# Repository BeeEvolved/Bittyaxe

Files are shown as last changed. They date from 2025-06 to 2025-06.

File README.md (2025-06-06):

<p align="center">
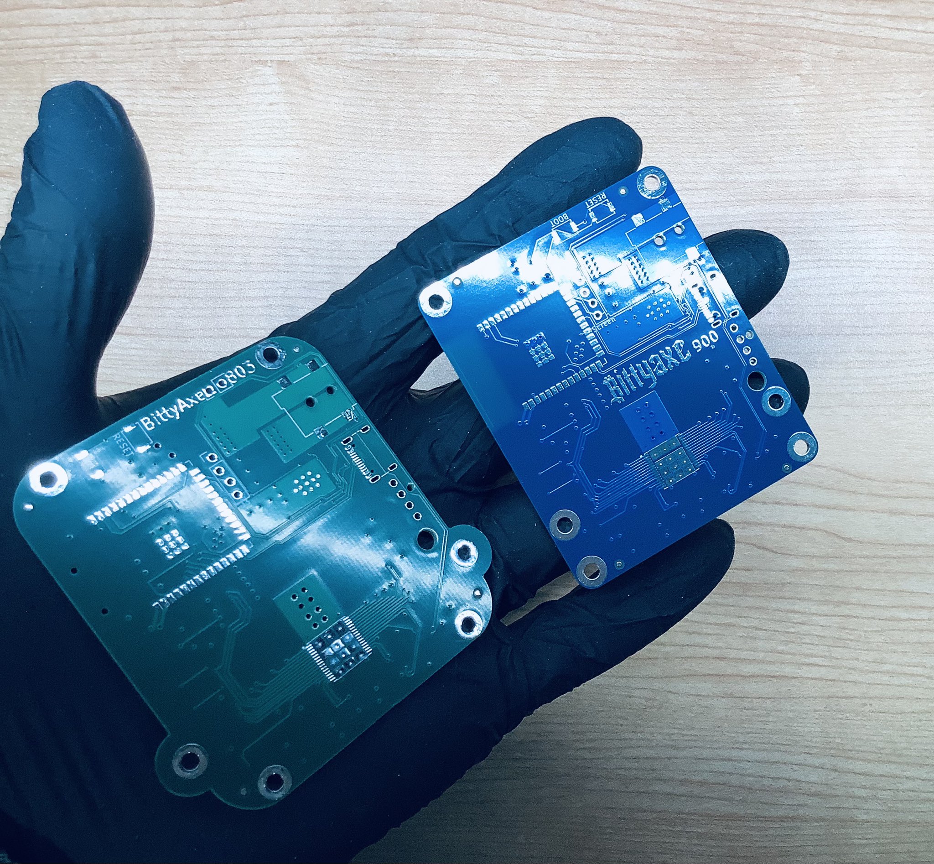
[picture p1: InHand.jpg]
Bittyaxe logo
  
</p>
<h1 align="center">itty-bitty open-source Bitcoin miner</h1>

The **BittyAxe** is a compact ASIC miner inspired by the [BitAxe Gamma](https://github.com/bitaxeorg/bitaxeGamma) design. It harnesses the power of the **BM1370** ASIC chip to achieve hash rates of approximately **1.2 TH/s** with an energy efficiency of **15 J/TH**.

---

## Features
- Custom, open-source compact thermal solution specifically designed for the BittyAxe
- Compact, space-saving form factor
- High-performance BM1370 ASIC chip
- ~1.2 TH/s hash rate
- 15 J/TH energy efficiency

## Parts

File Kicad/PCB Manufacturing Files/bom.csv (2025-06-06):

Designator | Footprint | Quantity | Value | LCSC Part #
C1, C21, C22, C23, C26, C27, C28, C30, C31, C32, C33, C34, C35, C36, C39, C40, C41, C42, C44, C45, C46, C48, C5, C7 | 0402 | 24 | 1uF
C10 | 0402 | 1 | 4.7uF
C11 | 0805 | 1 | 1000pF
C12, C25, C29, C37, C38, C47, C49, C52, C53, C8 | 0402 | 10 | 0.1uF
C13 | 0402 | 1 | 100pF
C14, C15, C16 | 0805 | 3 | 22uF
C17, C18, C19, C20, C43 | 1206 | 5 | 100uF
C2, C24 | 0805 | 2 | 10uF
C3, C4 | 1210 | 2 | 47uF
C50 | 0402 | 1 | 470pF
C6 | 0402 | 1 | 4700pF
C9 | 0402 | 1 | 2200pF
J1 | TENSILITY_54-00164 | 1 | 54-00164 | C431534
J5 | USB_C_Receptacle_GCT_USB4105-xx-A | 1 | USB_C_Receptacle_USB2.0
J6 | 470531000 | 1 | Conn_01x04
L1 | SLC1175-271MEC_COC | 1 | 300nH
R1 | 0402 | 1 | 8.25k
R10 | 0402 | 1 | 68.1k
R11 | 0402 | 1 | 10
R12 | 1206 | 1 | 1
R13, R14 | 0402 | 2 | 49.9
R15, R16, R17, R25 | 0402 | 4 | 10k
R19 | 0402 | 1 | 1k
R22, R23 | 0402 | 2 | 100
R24 | 0402 | 1 | 5.6k
R5 | 0402 | 1 | 14.7k
R6 | 0402 | 1 | RES 0 OHM JUMPER 1/16W
R8 | 0402 | 1 | 3.74k
R9 | 0402 | 1 | 11.8k
SCREEN | PinHeader_1x04_P2.54mm_Vertical_shifted | 1 | Conn_01x04
SW1, SW2 | SW_CS1213AGF260_CRS | 2 | GT-TC029B-H025-L1N
U10 | TSSOP-8_3x3mm_P0.65mm | 1 | EMC2101
U2 | LQFN40-CLIP | 1 | TPS546D24ARVFR
U3 | RT9080-33GJ5 | 1 | RT9080-33GJ5
U4 | ESP32-S3-WROOM-1 | 1 | ESP32-S3-WROOM-1
U5 | SOT-23-5 | 1 | MCP1824T-1202E/OT
U6 | SOT-23-5 | 1 | MCP1824T-0802E
U7 | SMD3225-4P | 1 | 25MHz | C5137262
U8 | BM1370 | 1 | BM1370_mode1
U9 | TSSOP-16_4.4x5mm_P0.65mm | 1 | SN74AVC4T774

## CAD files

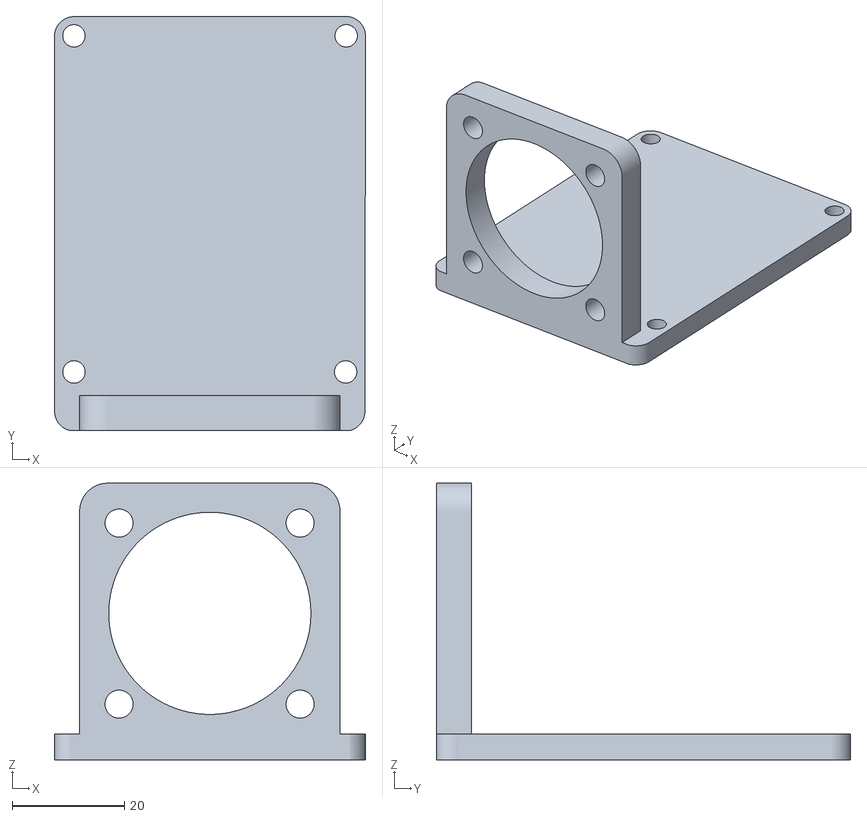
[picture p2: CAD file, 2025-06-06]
3D Print/Bittyaxe Air-Cooled Stand/Bittyaxe Air-Cooled Stand.stl
55.5 x 73.9 x 49.4

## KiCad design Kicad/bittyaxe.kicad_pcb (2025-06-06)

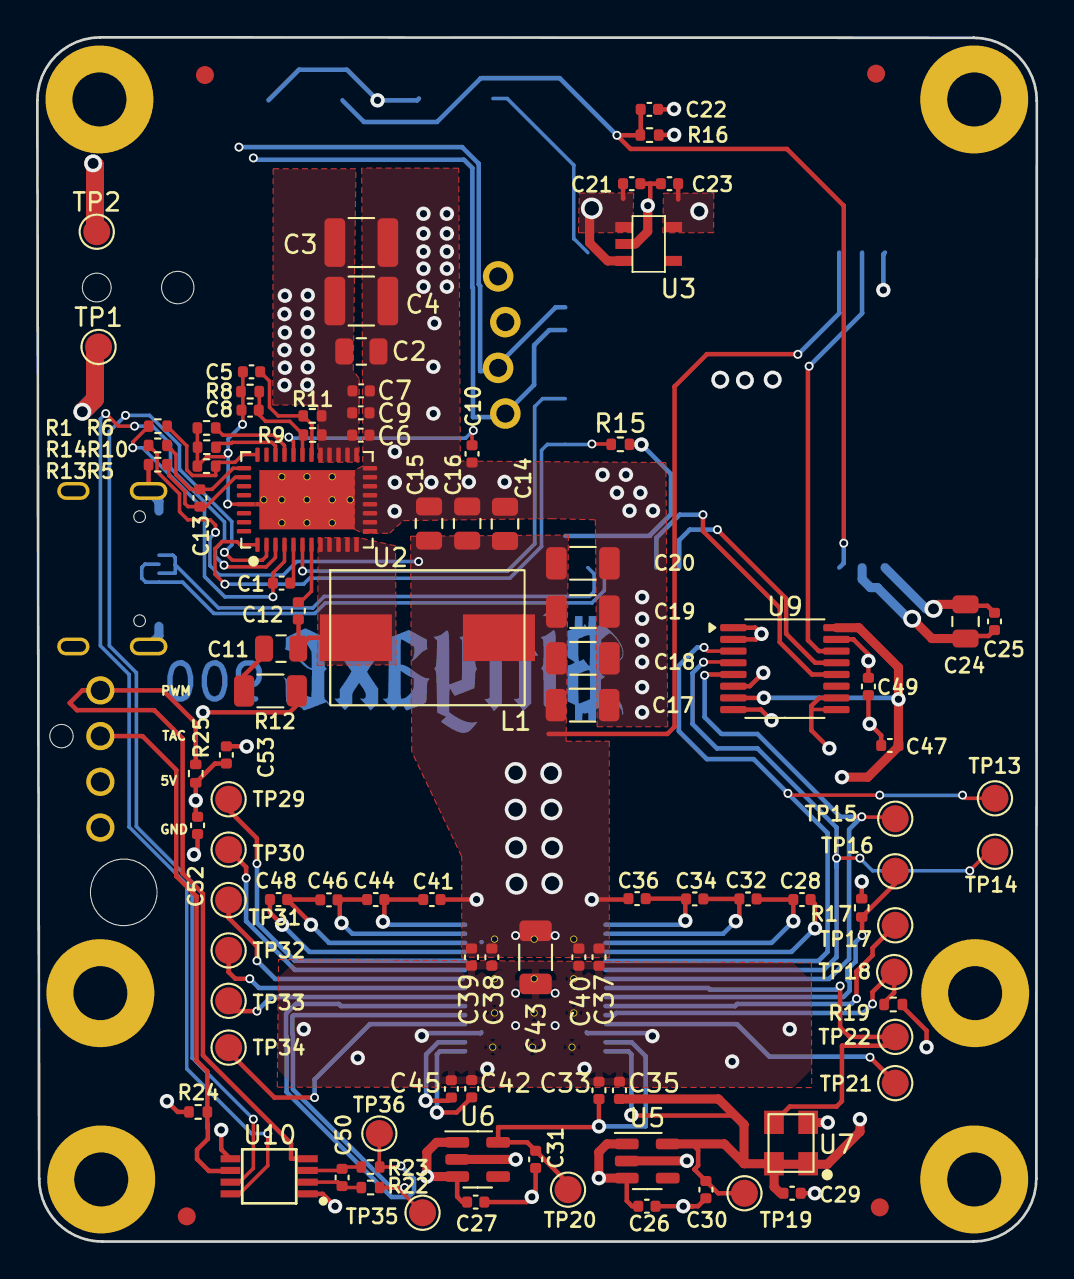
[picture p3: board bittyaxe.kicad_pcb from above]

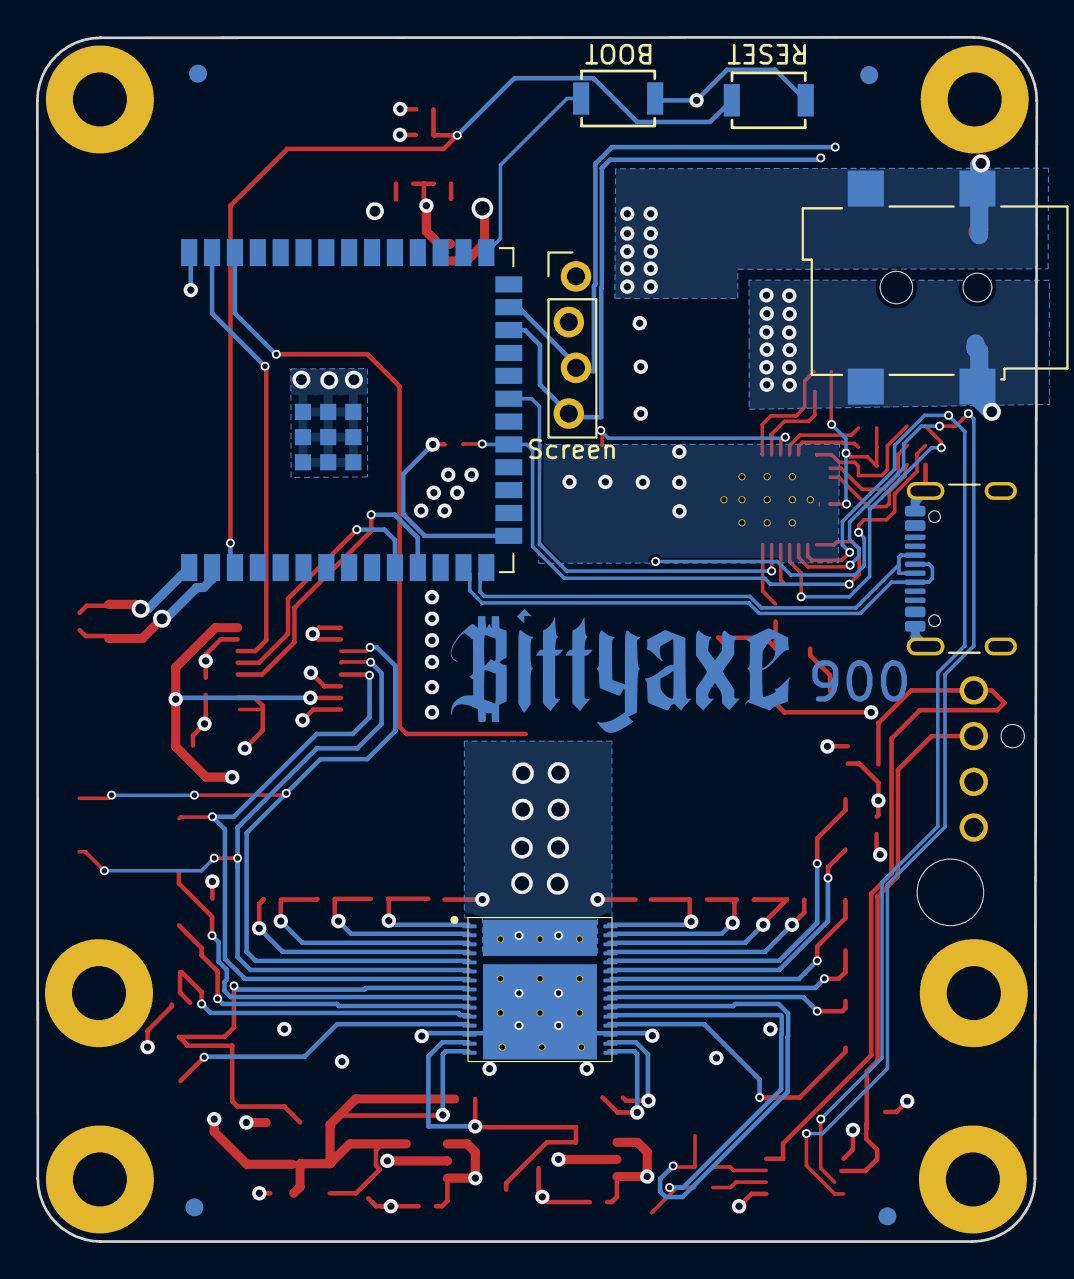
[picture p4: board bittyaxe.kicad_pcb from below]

Board: 4 copper layers, 55.5 x 66.9 mm, 122 parts (11 on the bottom side), 59 nets.

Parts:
C1, C5, C7, C21, C22, C23, C26, C27, C28, C30, C31, C32, C33, C34, C35, C36, C39, C40, C41, C42, C44, C45, C46, C48: 1uF; C_0402_1005Metric
C2, C24: 10uF; C_0805_2012Metric
C3, C4: 47uF; C_1210_3225Metric
C6: 4700pF; C_0402_1005Metric
C8, C12, C25, C29, C37, C38, C47, C49, C52, C53: 0.1uF; C_0402_1005Metric
C9: 2200pF; C_0402_1005Metric
C10: 4.7uF; C_0402_1005Metric
C11: 1000pF; C_0805_2012Metric
C13: 100pF; C_0402_1005Metric
C14, C15, C16: 22uF; C_0805_2012Metric
C17, C18, C19, C20, C43: 100uF; C_1206_3216Metric
C50: 470pF; C_0402_1005Metric
FID1, FID2, FID3, FID4, FID5, FID6, FID7, FID8: Fiducial; Fiducial_1mm_Mask2mm
Fan Cable Passthrough: MountingHole_3.7mm
H9, H9#2, H9#3, H9#4, H9#5, H9#6: MountingHole_Pad; MountingHole_3mm_Pad_Via
J1: 54-00164; TENSILITY_54-00164
J5: USB_C_Receptacle_USB2.0; USB_C_Receptacle_GCT_USB4105-xx-A
J6: Conn_01x04; 470531000
L1: 300nH; SLC1175-271MEC_COC
R1: 8.25k; R_0402_1005Metric
R5: 14.7k; R_0402_1005Metric
R6: RES 0 OHM JUMPER 1/16W; R_0402_1005Metric
R8: 3.74k; R_0402_1005Metric
R9: 11.8k; R_0402_1005Metric
R10: 68.1k; R_0402_1005Metric
R11: 10; R_0402_1005Metric
R12: 1; R_1206_3216Metric
R13, R14: 49.9; R_0402_1005Metric
R15, R16, R17, R25: 10k; R_0402_1005Metric
R19: 1k; R_0402_1005Metric
R22, R23: 100; R_0402_1005Metric
R24: 5.6k; R_0402_1005Metric
SW1, SW2: GT-TC029B-H025-L1N; SW_CS1213AGF260_CRS
Screen: Conn_01x04; PinHeader_1x04_P2.54mm_Vertical_shifted
T1: net-tie; NetTie-0.25mm
TP1, TP2, TP13, TP14, TP15, TP16, TP17, TP18, TP19, TP20, TP21, TP22, TP29, TP30, TP31, TP32, TP33, TP34, TP35, TP36: TestPoint; TestPoint_Pad_D1.5mm
U2: TPS546D24ARVFR; LQFN40-CLIP
U3: RT9080-33GJ5
U4: ESP32-S3-WROOM-1
U5: MCP1824T-1202E/OT; SOT-23-5
U6: MCP1824T-0802E; SOT-23-5
U7: 25MHz; SMD3225-4P
U8: BM1370_mode1; BM1370
U9: SN74AVC4T774; TSSOP-16_4.4x5mm_P0.65mm
U10: EMC2101; TSSOP-8_3x3mm_P0.65mm

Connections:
/3V3: C23.1, C24.1, C25.1, C49.1, R15.2, R16.1, R24.2, Screen.2, U3.5 (VOUT), U4.2 (3V3), U4.15 (GPIO3/TOUCH3/ADC1_CH2*), U9.15 (VCCB), U10.1 (VDD)
/5V: C2.1, C3.1, C4.1, C6.1, C7.1, C9.1, C21.1, C26.1, C27.1, C52.1, C53.1, J1.1, J6.2, R9.1, R11.1, R25.2, TP1.1, U2.21 (PVIN), U2.22 (PVIN), U2.23 (PVIN), U2.24 (PVIN), U2.25 (PVIN), U3.1 (VIN), U3.3 (EN), U5.1 (VIN), U5.3 (EN), U6.1 (VIN), U6.3 (EN)
/BM1370/0V8: C31.1, C33.1, TP20.1, U6.5 (VOUT), U8.14 (VDDIO_08_0)
/BM1370/1V2: C29.2, C30.1, C35.1, C47.1, TP19.1, U5.5 (VOUT), U7.1 (EN), U7.4 (VIN), U8.15 (VDDIO_12_0), U9.7 (DIR3), U9.16 (VCCA)
/BM1370/BI: R17.2, TP16.1, U8.9 (BI)
/BM1370/BO: TP33.1, U8.22 (BO)
/BM1370/CI: TP14.1, U8.6 (CI), U9.4 (A2)
/BM1370/CLKI: TP22.1, U7.3 (OUT), U8.8 (CLKI)
/BM1370/CLKO: TP32.1, U8.23 (CLKO)
/BM1370/CO: TP30.1, U8.25 (CO)
/BM1370/NRSTO: TP29.1, U8.26 (NRSTO)
/BM1370/PIN_MODE: TP34.1, U8.19 (PIN_MODE)
/BM1370/RI: TP31.1, U8.24 (RI)
/BM1370/RO: TP15.1, U8.7 (RO), U9.5 (A3)
/BM1370/RST_N: TP13.1, U8.5 (NRSTI), U9.3 (A1)
/BM1370/VDD1_0: C34.2, C36.1, U8.1 (VDD3_0)
/BM1370/VDD1_1: C41.2, C44.1, U8.30 (VDD3_1)
/BM1370/VDD2_0: C32.2, C34.1, U8.2 (VDD2_0)
/BM1370/VDD2_1: C44.2, C46.1, U8.29 (VDD2_1)
/BM1370/VDD3_0: C28.2, C32.1, U8.3 (VDD1_0)
/BM1370/VDD3_1: C46.2, C48.1, U8.28 (VDD1_1)
/ESP32/EN: C22.1, R16.2, SW1.2, U4.3 (EN)
/ESP32/IO0: SW2.2, U4.27 (GPIO0/BOOT*)
/ESP32/USB_D+: J5.A6 (D+), J5.B6 (D+), U4.14 (GPIO20/U1CTS/ADC2_CH9/CLK_OUT1/USB_D+)
/ESP32/USB_D-: J5.A7 (D-), J5.B7 (D-), U4.13 (GPIO19/U1RTS/ADC2_CH8/CLK_OUT2/USB_D-)
/Fan/FAN_PWM: J6.4, R25.1, U10.4 (FAN)
/Fan/FAN_TACH: J6.3, R24.1, U10.6 (ALERT/TACH)
/Fan/TEMP_DN: C50.2, R22.1, U10.3 (DN)
/Fan/TEMP_DP: C50.1, R23.2, U10.2 (DP)
/Fan/TEMP_N: R22.2, TP36.1, U8.21 (TEMP_N)
/Fan/TEMP_P: R23.1, TP35.1, U8.20 (TEMP_P)
/Power/AGND: C5.1, C8.2, R5.1, R6.2, R8.2, R10.2, T1.1, U2.37 (AGND)
/Power/PGOOD: R15.1, U2.1 (PGD), U4.19 (GPIO11/TOUCH11/ADC2_CH0/FSPID/FSPIIO5/S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)
/Power/PMB_ALRT: U2.6 (SMB_ALRT), U4.21 (GPIO13/TOUCH13/ADC2_CH2/FSPIQ/FSPIIO7/S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)
/Power/SW: C11.2, C12.2, L1.1, U2.8 (SW), U2.9 (SW), U2.10 (SW), U2.11 (SW), U2.12 (SW)
/RST: U4.39 (GPIO1/TOUCH1/ADC1_CH0), U9.14 (B1)
/RX: U4.11 (GPIO18/U1RXD/ADC2_CH7/CLK_OUT3), U9.12 (B3)
/SCL: Screen.3, U2.3 (PMB_CLK), U4.25 (GPIO48/SPICLK_N/SUBSPICLK_N_DIFF), U10.8 (SMCLK)
/SDA: Screen.4, U2.2 (PMB_DATA), U4.24 (GPIO47/SPICLK_P/SUBSPICLK_P_DIFF), U10.7 (SMDATA)
/TX: U4.10 (GPIO17/U1TXD/ADC2_CH6), U9.13 (B2)
/VDD: C14.1, C15.1, C16.1, C17.1, C18.1, C19.1, C20.1, C36.2, C37.1, C38.1, C39.1, C40.1, C41.1, C43.1, L1.2, R14.1, U4.38 (GPIO2/TOUCH2/ADC1_CH1), U8.31 (VDD), U8.33
GND: C2.2, C3.2, C4.2, C6.2, C7.2, C9.2, C10.2, C14.2, C15.2, C16.2, C17.2, C18.2, C19.2, C20.2, C21.2, C22.2, C23.2, C24.2, C25.2, C26.2, C27.2, C28.1, C29.1, C30.2, C31.2, C33.2, C35.2, C37.2, C38.2, C39.2, C40.2, C42.2, C43.2, C45.2, C47.2, C48.2, C49.2, C52.2, C53.2, H9.1, H9#2.1, H9#3.1, H9#4.1, H9#5.1, H9#6.1, J1.2, J1.3, J5.A1 (GND), J5.B1 (GND), J5.S1 (SHIELD), J6.1, R12.1, R13.2, R17.1, R19.1, SW1.1, SW2.1, Screen.1, T1.2, TP2.1, U2.13 (PGND), U2.14 (PGND), U2.15 (PGND), U2.16 (PGND), U2.17 (PGND), U2.18 (PGND), U2.19 (PGND), U2.20 (PGND), U2.41 (PAD), U3.2 (GND), U4.1 (GND), U4.40 (GND), U4.41 (GND), U5.2 (GND), U6.2 (GND), U7.2 (GND), U8.4 (VSS), U8.13 (PLL_VSS), U8.18 (VSS), U8.27 (VSS), U8.32 (VSS), U8.33, U9.1 (DIR1), U9.2 (DIR2), U9.6 (A4), U9.8 (DIR4), U9.9 (OE), U9.10 (GND), U10.5 (GND)
unnamed: C11.1, R12.2
unnamed: C5.2, R11.2, U2.26 (AVIN)
unnamed: C12.1, U2.7 (BOOT)
unnamed: C1.2, R1.1, U2.4 (BP1V5)
unnamed: C1.1, U2.5 (DRTN)
unnamed: C8.1, R8.1, R9.2, U2.27 (EN/UVLO)
unnamed: C13.2, R13.1, U2.34 (GOSNS)
unnamed: R1.2, R5.2, U2.32 (MSEL1)
unnamed: R6.1, U2.29 (MSEL2)
unnamed: C10.1, U2.28 (VDD5)
unnamed: C13.1, R14.2, U2.33 (VOSNS)
unnamed: R10.1, U2.30 (VSEL)
unnamed: TP21.1, U8.12 (INV_CLKO)
unnamed: R19.2, TP18.1, U8.11 (LITE_PAD)
unnamed: TP17.1, U8.10 (ROSC_SEL)
unnamed: C45.1, U8.17 (VDDIO_08_1)
unnamed: C42.1, U8.16 (VDDIO_12_1)
